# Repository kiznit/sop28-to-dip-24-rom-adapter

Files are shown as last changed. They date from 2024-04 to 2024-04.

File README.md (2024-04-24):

# sop28-to-dip-24-rom-adapter
ROM adapter board from sop-28 to dip-24.

I recently acquired a Color Computer 1 (CoCo 1) that came with Color Basic 1.1 and no Extended Color Basic. The CoCo 1 I have has the revision E motherboard. It contains two 24-PIN sockets next to each other for the Color Basic (CB) and Extended Color Basic (ECB) ROMs. These ROMs are extremely difficult to find and so are 24-PIN EPROMs.

I decided to use the 28C64 EEPROMs to upgrade my machine. The main difficulty is that space is extremely limited around the sockets and there is only a 0.2" (5.08 mm) gap between the two sockets. This means that I needed an adapter board that was no more than 0.8" (20.32 mm) wide. The usual DIP-28 to DIP-24 adapters will not fit. The solution was to use a SOP-28 EEPROM instead of a DIP-28 and to design my own adapter.

This adapter as of revision 2B will only work with the 28C64, not the 28C256 or the 27 series. This is because PIN 1 is left unconnected as per the 28C64 specifications and I didn't provide a way to connect that PIN to ground or a pull-up resistor. PIN 26 is grounded but should probably have been left floating. The 4.7K pull-up resistor is used to bring PIN 27 (/WE) high.

The **bin** folder contains a zip file that can be uploaded directly to JLBPCB for production.

Revision 2B is the same as revision 2 but with a smaller footprint.

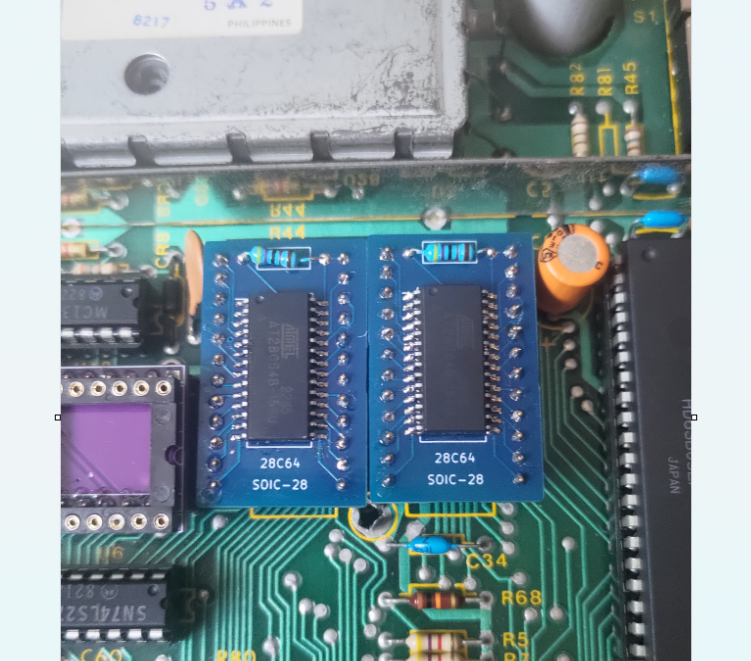
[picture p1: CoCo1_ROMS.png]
CoCo 1 with two ROM adapters (revision 2)


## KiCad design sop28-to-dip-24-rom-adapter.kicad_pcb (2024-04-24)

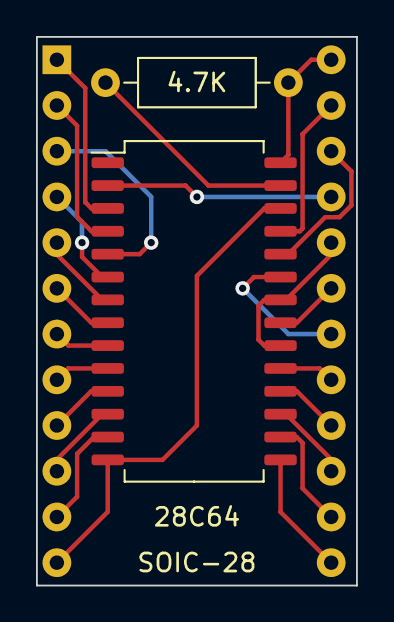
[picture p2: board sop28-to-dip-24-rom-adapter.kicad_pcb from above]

Board: 2 copper layers, 17.8 x 30.5 mm, 3 parts (0 on the bottom side), 25 nets.

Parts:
4.7K: 4.7K; R_Axial_DIN0207_L6.3mm_D2.5mm_P10.16mm_Horizontal
28C64: EPROM_28; SOIC-28W_7.5x18.7mm_P1.27mm
U2: ROM_24; DIP-24_W15.24mm-Notch

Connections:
/A0: 28C64.10 (A0), U2.8 (A0)
/A1: 28C64.9 (A1), U2.7 (A1)
/A2: 28C64.8 (A2), U2.6 (A2)
/A3: 28C64.7 (A3), U2.5 (A3)
/A4: 28C64.6 (A4), U2.4 (A4)
/A5: 28C64.5 (A5), U2.3 (A5)
/A6: 28C64.4 (A6), U2.2 (A6)
/A7: 28C64.3 (A7), U2.1 (A7)
/A8: 28C64.25 (A8), U2.23 (A8)
/A9: 28C64.24 (A9), U2.22 (A9)
/A10: 28C64.21 (A10), U2.19 (A10)
/A11: 28C64.23 (A11), U2.18 (A11)
/A12: 28C64.2 (A12), U2.21 (A12)
/D0: 28C64.11 (D0), U2.9 (D0)
/D1: 28C64.12 (D1), U2.10 (D1)
/D2: 28C64.13 (D2), U2.11 (D2)
/D3: 28C64.15 (D3), U2.13 (D3)
/D4: 28C64.16 (D4), U2.14 (D4)
/D5: 28C64.17 (D5), U2.15 (D5)
/D6: 28C64.18 (D6), U2.16 (D6)
/D7: 28C64.19 (D7), U2.17 (D7)
GND: 28C64.14 (GND), 28C64.26, U2.12 (GND)
unnamed: 28C64.20 (~CS), 28C64.22 (~OE), U2.20 (~CE)
unnamed: 4.7K.2, 28C64.27 (~WE)
VCC: 4.7K.1, 28C64.28 (VCC), U2.24 (VCC)

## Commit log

2024-04-15 Revision 2.
    [sop28-to-dip-24-rom-adapter-B_Cu.gbl, sop28-to-dip-24-rom-adapter-B_Mask.gbs, sop28-to-dip-24-rom-adapter-B_Paste.gbp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]
2024-04-24 Revision 2B.
    [sop28-to-dip-24-rom-adapter-B_Cu.gbl, sop28-to-dip-24-rom-adapter-B_Mask.gbs, sop28-to-dip-24-rom-adapter-B_Paste.gbp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]
